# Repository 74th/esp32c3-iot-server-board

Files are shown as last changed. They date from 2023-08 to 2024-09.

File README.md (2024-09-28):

# IoT Server Board - ESP32C3

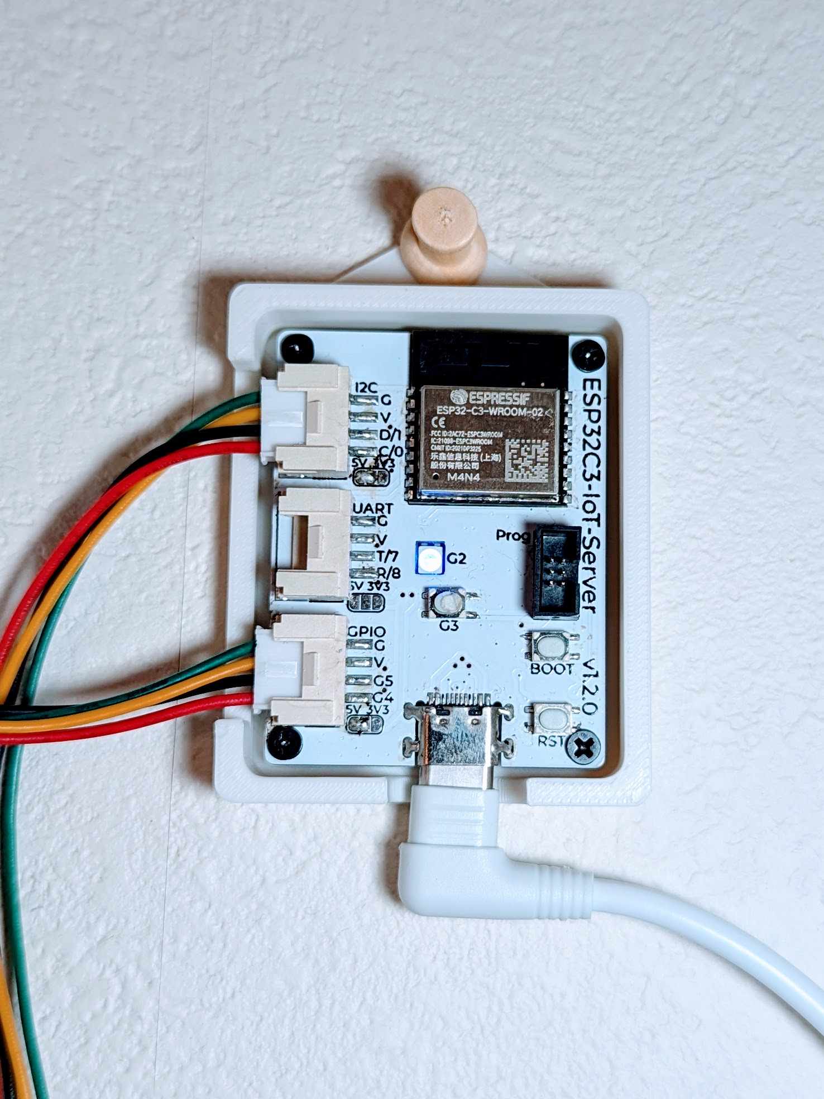
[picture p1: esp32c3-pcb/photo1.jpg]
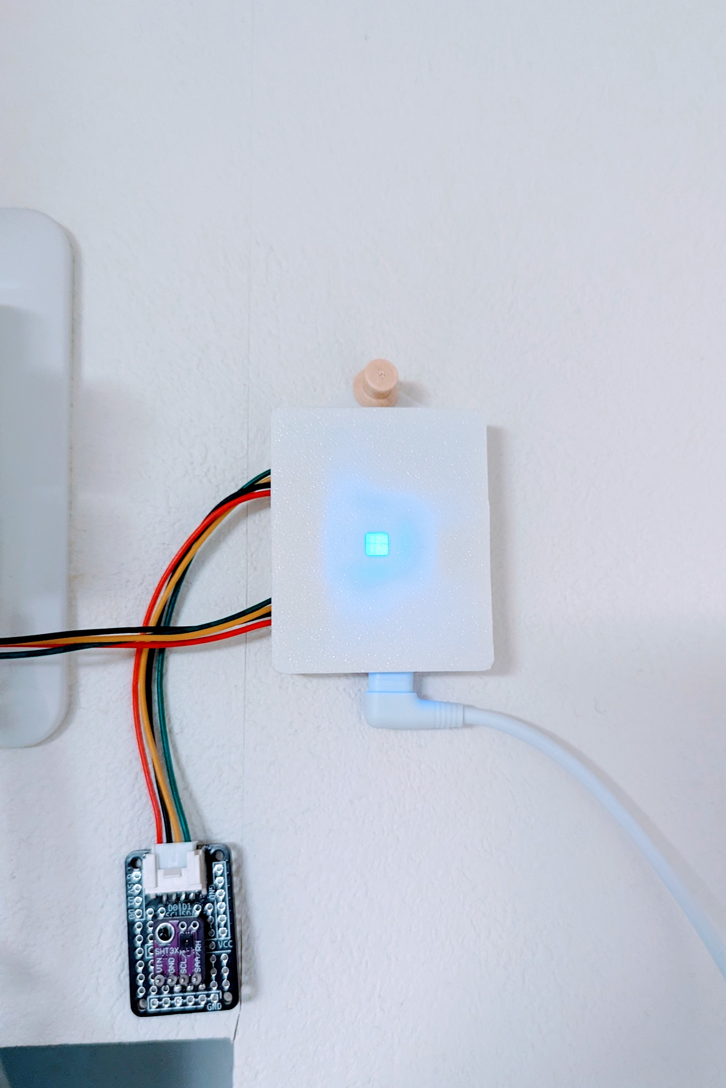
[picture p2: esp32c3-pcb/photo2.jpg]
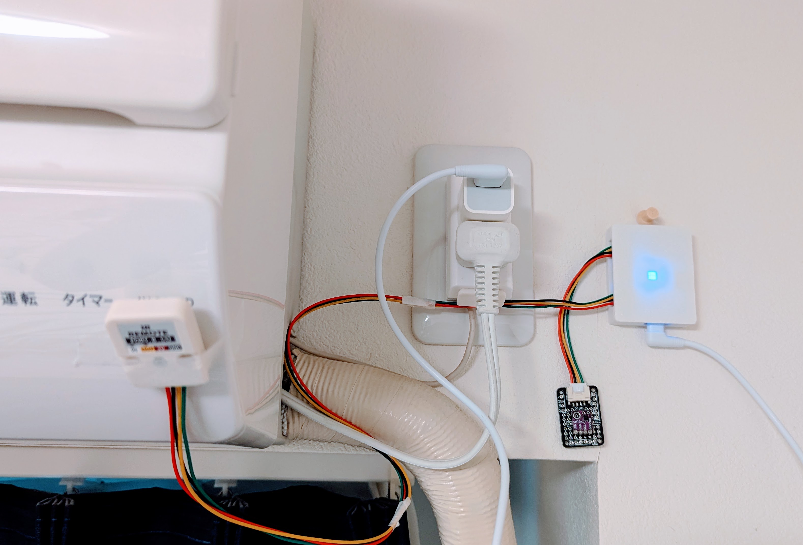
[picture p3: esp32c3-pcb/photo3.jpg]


Board for converting Grove device to IoT Server using ESP32-C3-WROOM-02.

ESP32-C3-WROOM-02 を使った Grove デバイスを IoT Server 化するためのボード。

74thが作成するファームウェアについてはこちら https://github.com/74th/esp32c3-iot-server-firmware

## features

- ESP32-C3 onboard for WiFi connectivity
- Three Grove ports are equipped.
- Selectable 5V or 3.3V VCC for Grove port
- RGB LED for indicator
- Button for operation
- USB Type-C port for firmware rewriting

### 🇯🇵

- ESP32-C3 搭載で、WiFi 接続が可能
- Grove ポートを 3 ポート搭載
- Grove ポートの VCC は 5V、3.3V を選択可能
- インジケータ用の RGB LED 搭載
- 操作用のボタン搭載
- USB Type-C ポートで、ファームウェアの書き換え可能

## v1.2.0

- Semantics: [PDF](./esp32c3-pcb/esp32c3-iot-server-v1.2.0-semantics.pdf) [kicanvas](https://kicanvas.org/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)
- PCB [kicanvas](https://kicanvas.org/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)

### BOM

| Reference | Name | Quantity |
| --- | --- | --- |
| C1 | Capacitor 0805 1uF | 1 |
| C2, C4 | Capacitor 0805 100nF | 2 |
| C3, C5-C8 | Capacitor 0805 10uF | 5 |
| CH1 | HY2.0 Socket SMD 4Pin - I2C | 1 |
| CH2 | HY2.0 Socket SMD 4Pin - UART | 1 |
| CH3 | HY2.0 Socket SMD 4Pin - GPIO | 1 |
| D1 | RGBLED 3528 SK6812MINI-E | 1 |
| J1 | Box Pin Header 2x3 Pitch 1.27mm | 1 |
| J2 | USB Type-C Receptacle - USB2.0_C_v3 | 1 |
| R1, R2 | Capacitor 0805 1kΩ (NC) | 2 |
| R3, R4, R10 | Capacitor 0805 10kΩ | 3 |
| R5, R9 | Capacitor 0805 5.1kΩ | 2 |
| R6, R7 | Capacitor 0805 10Ω | 2 |
| R8 | Capacitor 0805 56kΩ | 1 |
| SW1 | Button SKRPABE010 | 1 |
| SW2 | Button SKRPABE010 | 1 |
| SW3 | Button SKRPABE010 | 1 |
| U1 | WiFi MCU Module ESP32-C3-WROOM-02 | 1 |
| U2 | Regulator 3.3V SOT-223 AMS1117-3.3 | 1 |
| U3 | USB Power Protection IC SOT-23-6L CH217K | 1 |

## v1.1.1

### BOM

| Reference | Name | Quantity |
| --- | --- | --- |
| C1 | Capacitor 0805 1uF | 1 |
| C2, C3 | Capacitor 0805 100nF | 2 |
| C4, C5 | Capacitor 0805 10uF | 2 |
| CH1 | HY2.0 Socket SMD 4Pin - I2C | 1 |
| CH2 | HY2.0 Socket SMD 4Pin - UART | 1 |
| CH3 | HY2.0 Socket SMD 4Pin - GPIO | 1 |
| D1 | RGBLED 3528 SK6812MINI-E | 1 |
| F1 | PolyFuse 1812 KT6-1100SMDI (NC) | 1 |
| J1 | Box Pin Header 2x3 Pitch 1.27mm | 1 |
| J2 | USB Type-C Receptacle - USB2.0_C_v3 | 1 |
| R1, R2, R5-R7 | Capacitor 0805 10kF | 5 |
| R3, R4 | Capacitor 0805 5.1kF | 2 |
| R8 | Capacitor 0805 42kF | 1 |
| SW1 | Button SKRPABE010 | 1 |
| SW2 | Button SKRPABE010 | 1 |
| SW3 | Button SKRPABE010 | 1 |
| U1 | WiFi MCU Module ESP32-C3-WROOM-02 | 1 |
| U2 | Regulator 3.3V SOT-223 AMS1117-3.3 | 1 |
| U4 | USB Power Protection IC SOT-26 CH214K | 1 |

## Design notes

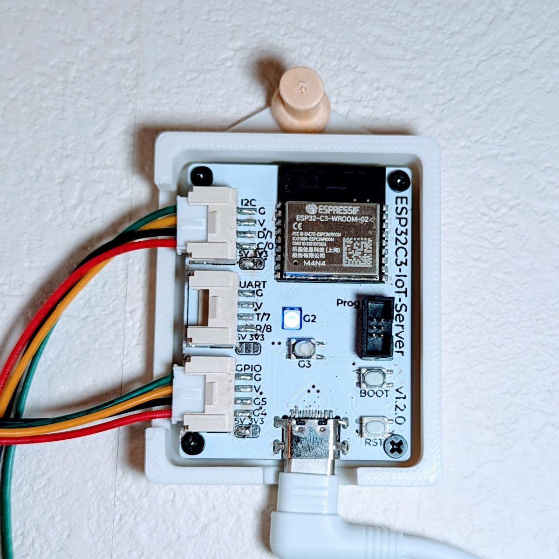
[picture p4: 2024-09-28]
esp32c3-pcb/g035-esp32c3-iot-server.jpg

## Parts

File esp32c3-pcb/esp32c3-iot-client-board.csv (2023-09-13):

Reference | Value | Footprint | 数量
C1 | 1u | $74th:Capacitor_0805_2012 | 1
C2, C4 | 100n | $74th:Capacitor_0805_2012 | 2
C3, C5-C8 | 10u | $74th:Capacitor_0805_2012 | 5
CH1 | I2C | $74th:HY2.0_Socket_SMD_4Pin | 1
CH2 | UART | $74th:HY2.0_Socket_SMD_4Pin | 1
CH3 | GPIO | $74th:HY2.0_Socket_SMD_4Pin | 1
D1 | SK6812MINI | $74th:YS-SK6812MINI-E-BACK-RIGHT | 1
J1 | Prog | $74th:BoxPinHeader_2x03_P1.27mm_Vertical | 1
J2 | USB2.0_C_v3 | $74th:USB-C-12-Pin-MidMount-ali-v5 | 1
JP1-JP3 | Jumper_3_Open | $74th:VCC_Selector_Jumper | 3
R1, R2 | 1k(NC) | $74th:Capacitor_0805_2012 | 2
R3, R4, R10 | 10k | $74th:Capacitor_0805_2012 | 3
R5, R9 | 5.1k | $74th:Capacitor_0805_2012 | 2
R6, R7 | 27.4 | $74th:Capacitor_0805_2012 | 2
R8 | 56k | $74th:Capacitor_0805_2012 | 1
SW1 | G3 | $74th:SKRPABE010 | 1
SW2 | BOOT | $74th:SKRPABE010 | 1
SW3 | RST | $74th:SKRPABE010 | 1
U1 | ESP32-C3-WROOM-02 | $74th-imported:ESP32-C3-WROOM-02 | 1
U2 | AMS1117-3.3 | Package_TO_SOT_SMD:SOT-223-3_TabPin2 | 1
U3 | CH217K | Package_TO_SOT_SMD:SOT-23-6 | 1

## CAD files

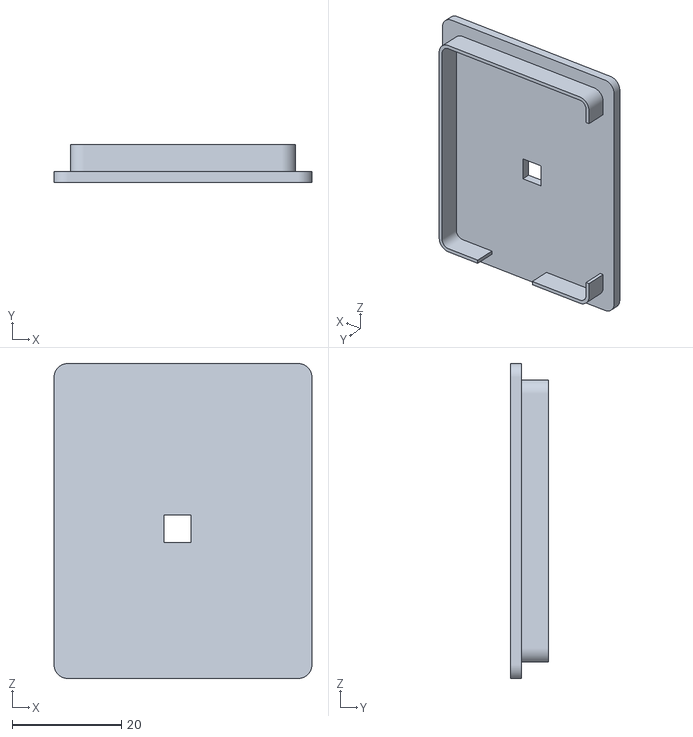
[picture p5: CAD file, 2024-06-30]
case/esp32c3-iot-client-board_case-lid_v1.1.0.stl
47.2 x 7.00 x 57.6

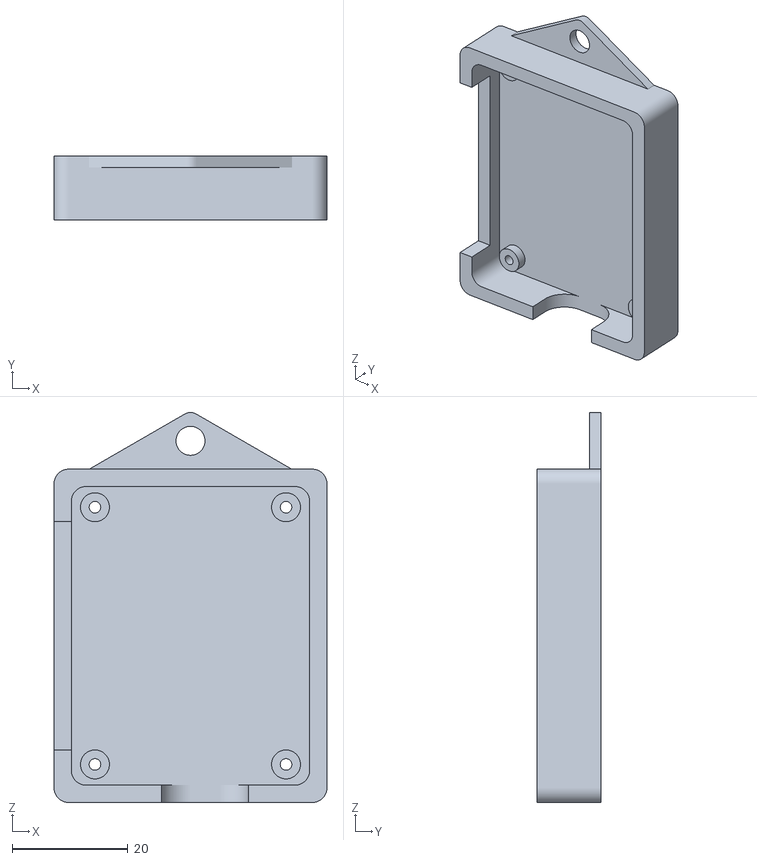
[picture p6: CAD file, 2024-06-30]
case/esp32c3-iot-client-board_case-bottom_v1.1.0.stl
47.2 x 11.0 x 67.4

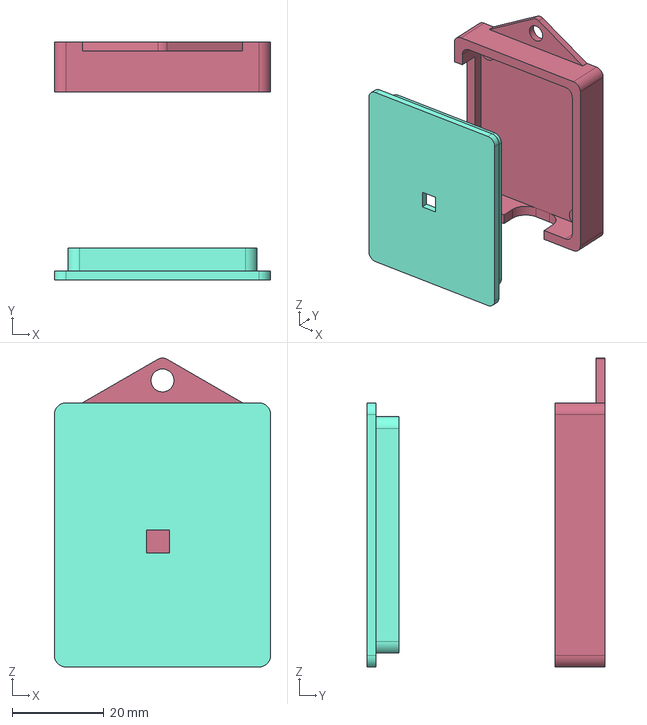
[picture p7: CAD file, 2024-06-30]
case/esp32c3-iot-client-board_case.FCStd
47.2 x 52.0 x 67.4 mm
lid

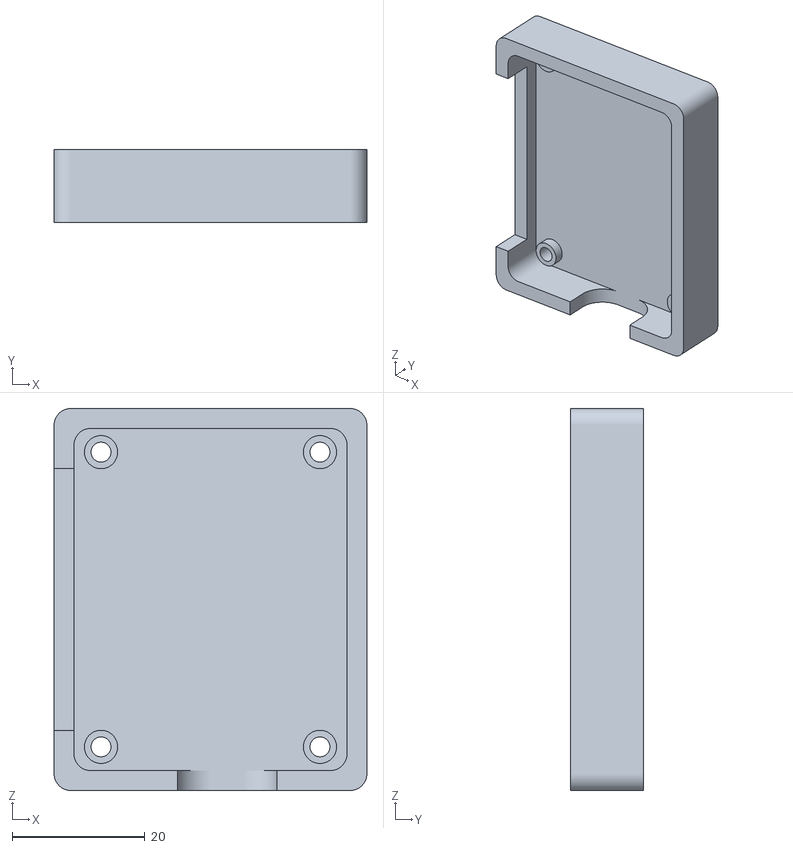
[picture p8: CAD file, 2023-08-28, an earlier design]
case/esp32c3-iot-client-board_case-bottom_v1.0.0.stl
47.2 x 11.0 x 57.6

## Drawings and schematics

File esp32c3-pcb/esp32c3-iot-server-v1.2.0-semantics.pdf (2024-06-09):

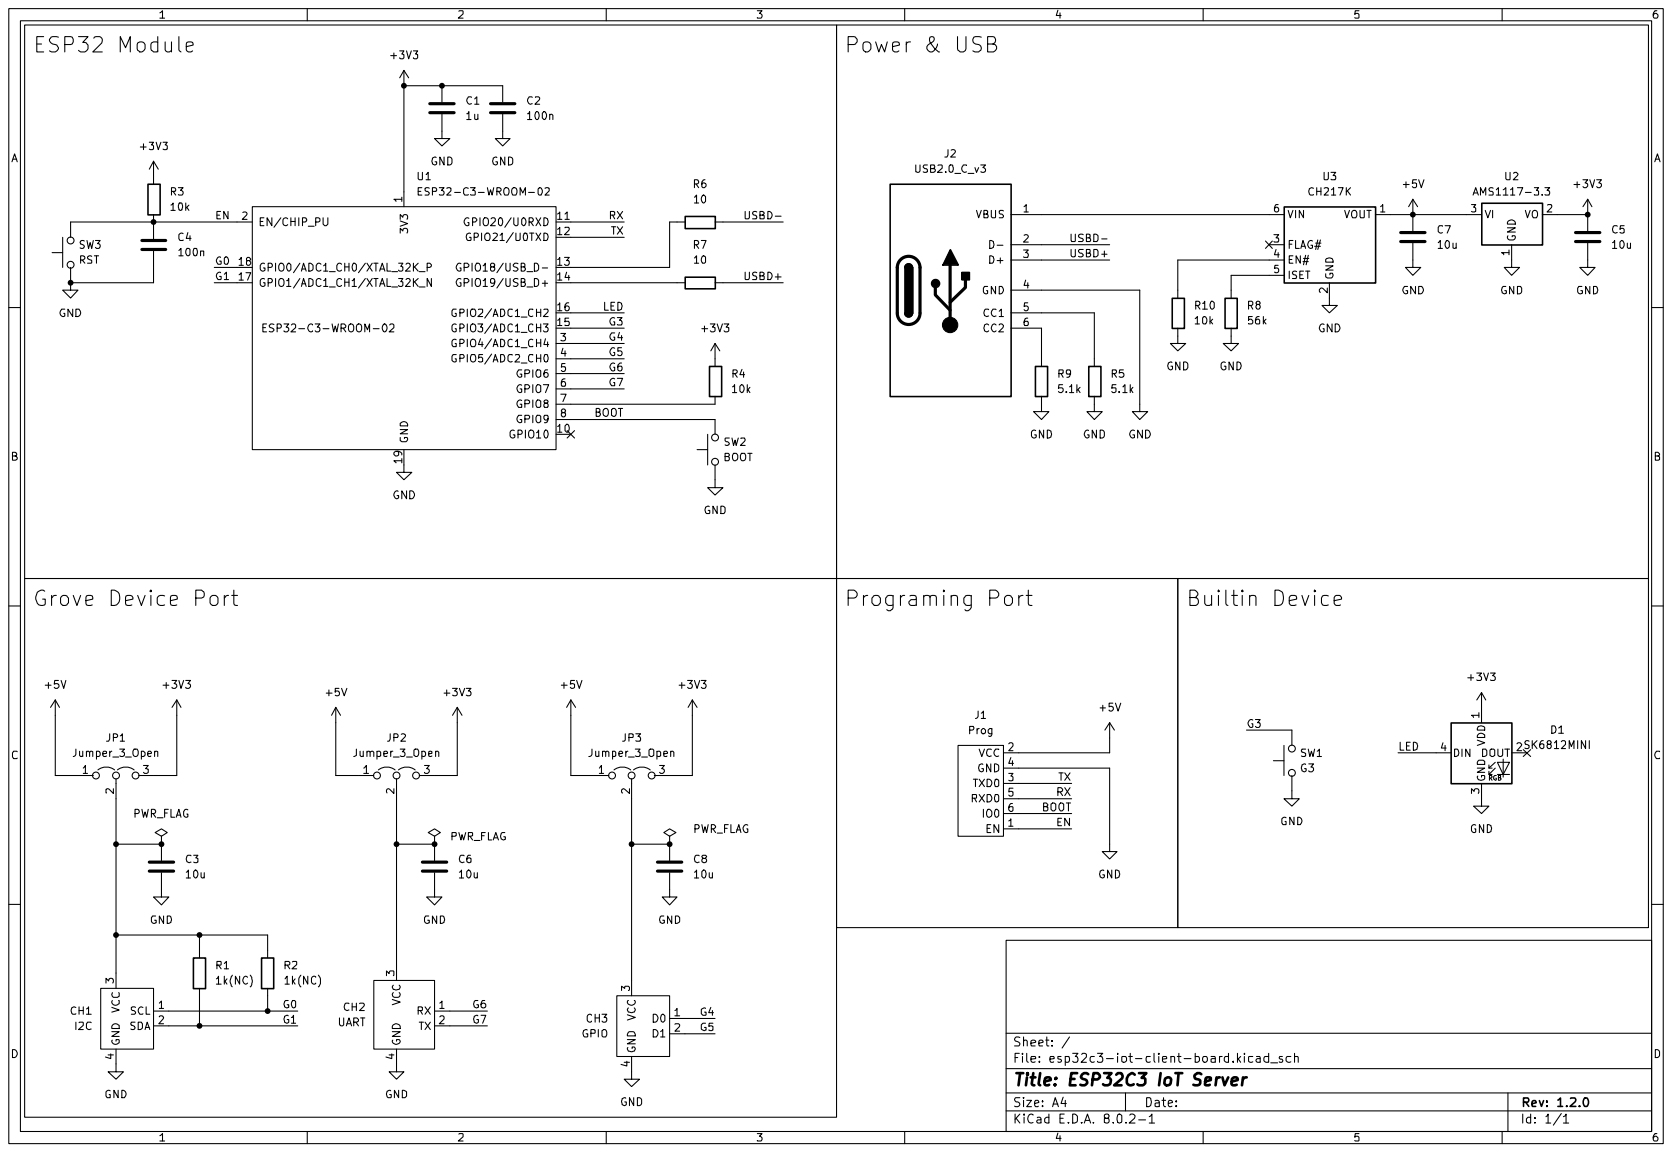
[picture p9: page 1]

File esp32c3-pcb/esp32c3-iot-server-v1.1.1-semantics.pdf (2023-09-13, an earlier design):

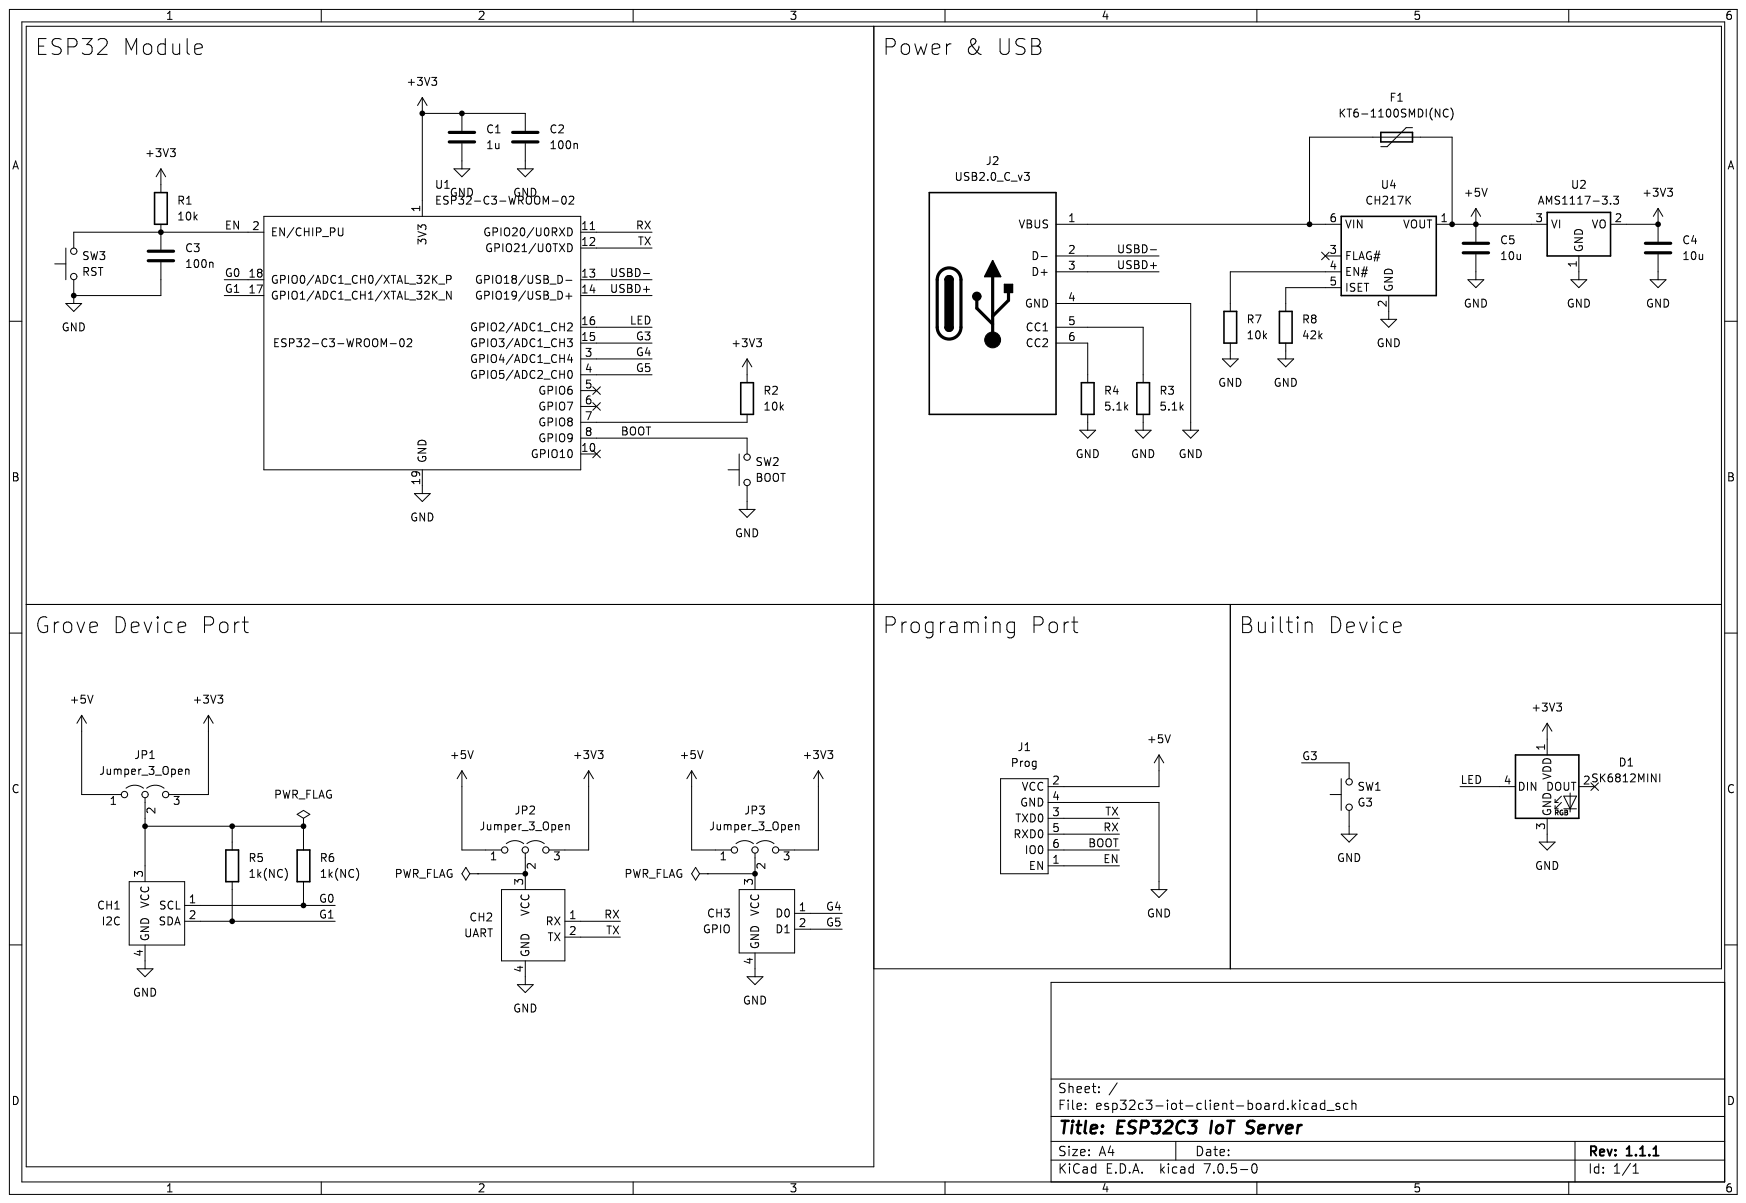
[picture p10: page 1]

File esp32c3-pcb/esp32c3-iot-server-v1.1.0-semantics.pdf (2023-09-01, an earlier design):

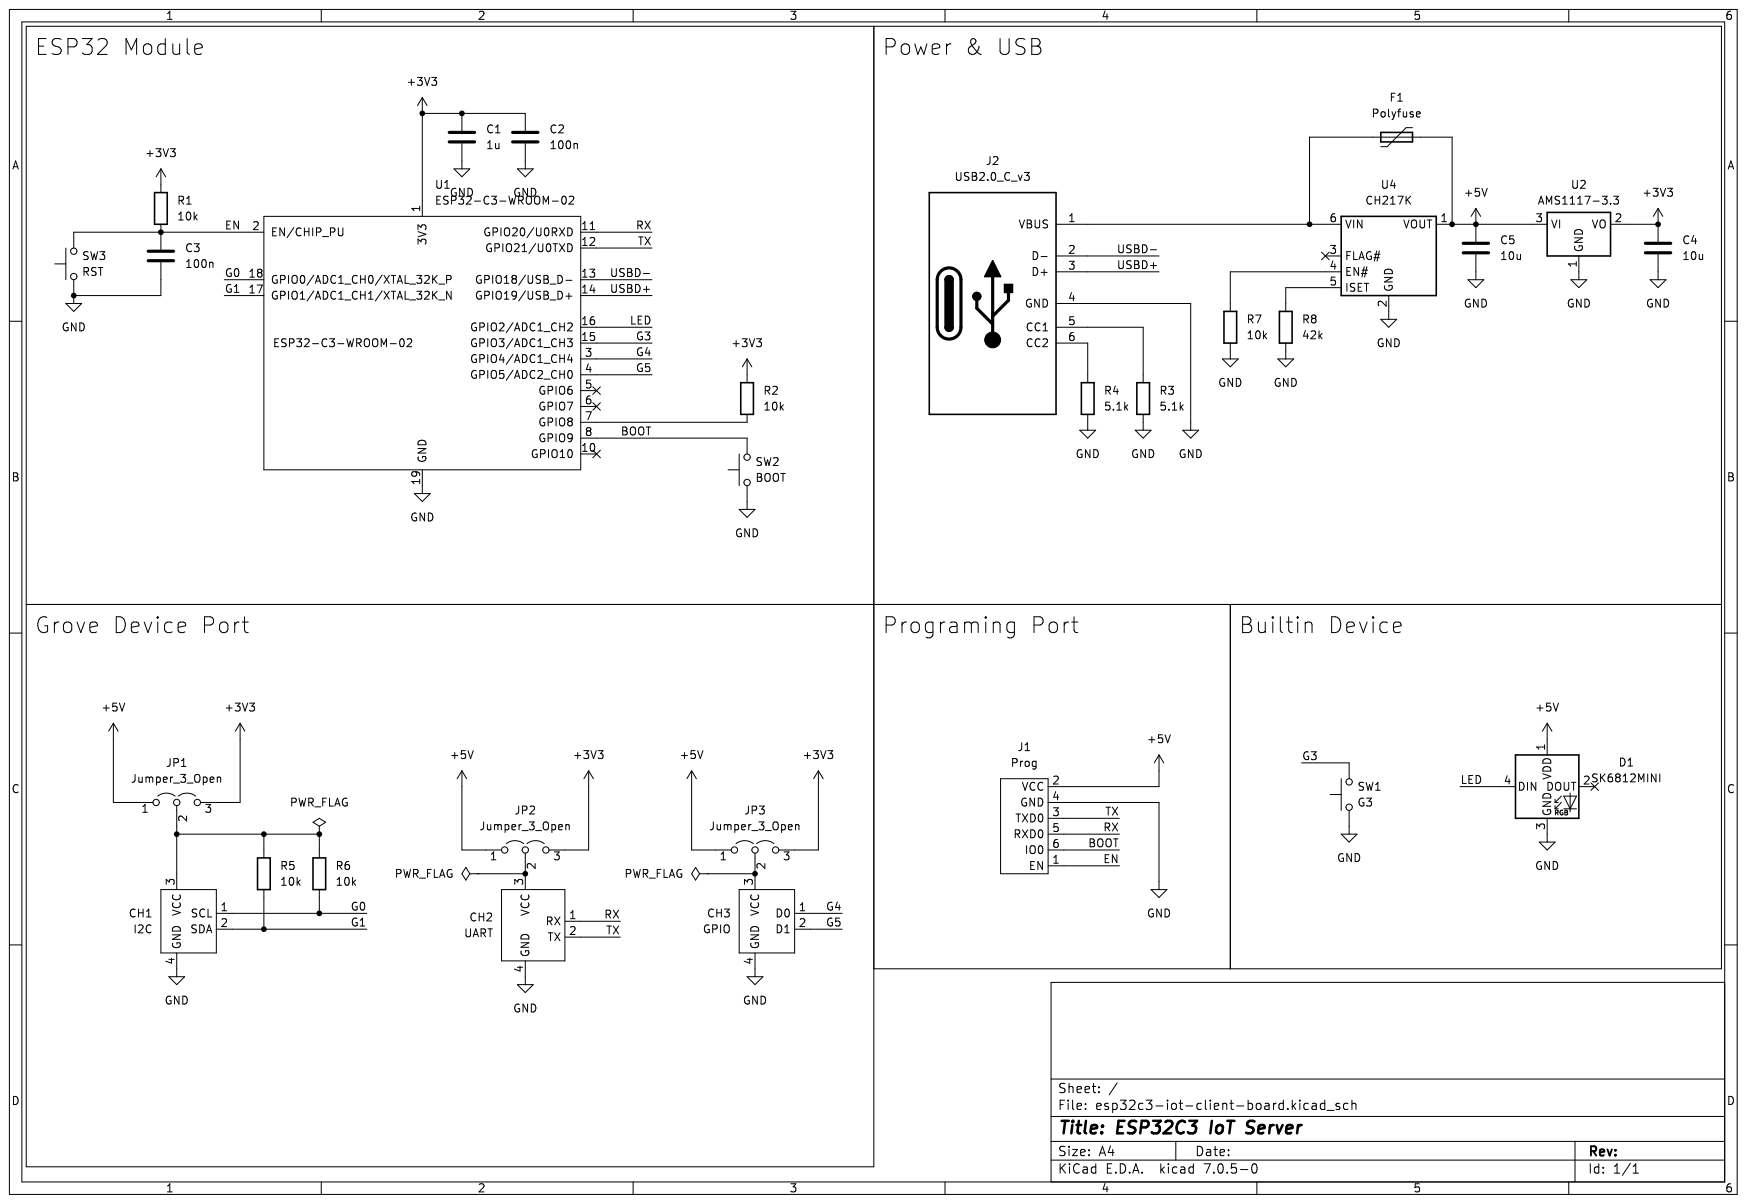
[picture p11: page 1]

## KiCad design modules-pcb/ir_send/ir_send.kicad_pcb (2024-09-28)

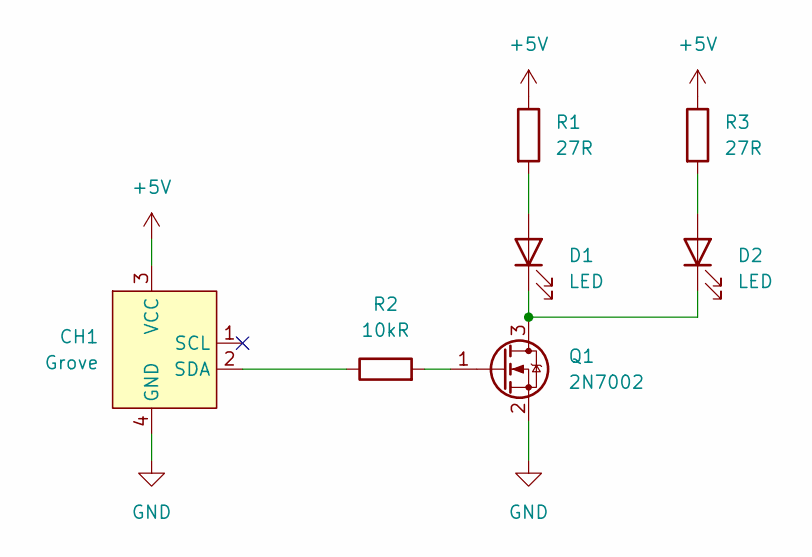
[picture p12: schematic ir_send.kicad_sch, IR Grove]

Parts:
CH1: Grove; Connector_HY-2.0_SMD_4Pin
D1, D2: LED; PinOut_Pin_2_1GND
Q1: 2N7002; Package_SOT-23
R1, R3: 27R; Register_0805_2012
R2: 10kR; Register_0805_2012

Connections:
+5V: CH1.3 (VCC), R1.1, R3.1
GND: CH1.4 (GND), Q1.2 (S)
unnamed: CH1.2 (SDA), R2.1
unnamed: D1.2 (A), R1.2
unnamed: D1.1 (K), D2.1 (K), Q1.3 (D)
unnamed: D2.2 (A), R3.2
unnamed: Q1.1 (G), R2.2

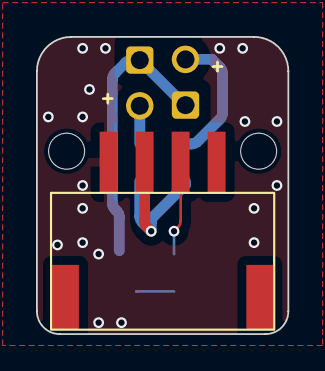
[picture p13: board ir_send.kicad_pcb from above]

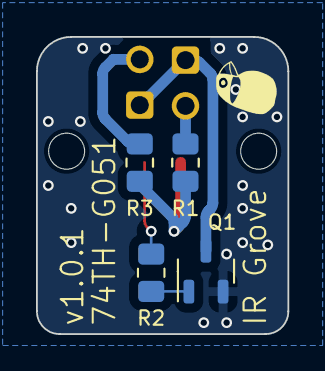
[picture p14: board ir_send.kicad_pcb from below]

Board: 2 copper layers, 14.0 x 16.5 mm, 10 parts (5 on the bottom side), 7 nets.

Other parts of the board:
M2, M2#2: Hole_M2_2.0
MISC-ICON: LOGO; Logo_74th_4mm

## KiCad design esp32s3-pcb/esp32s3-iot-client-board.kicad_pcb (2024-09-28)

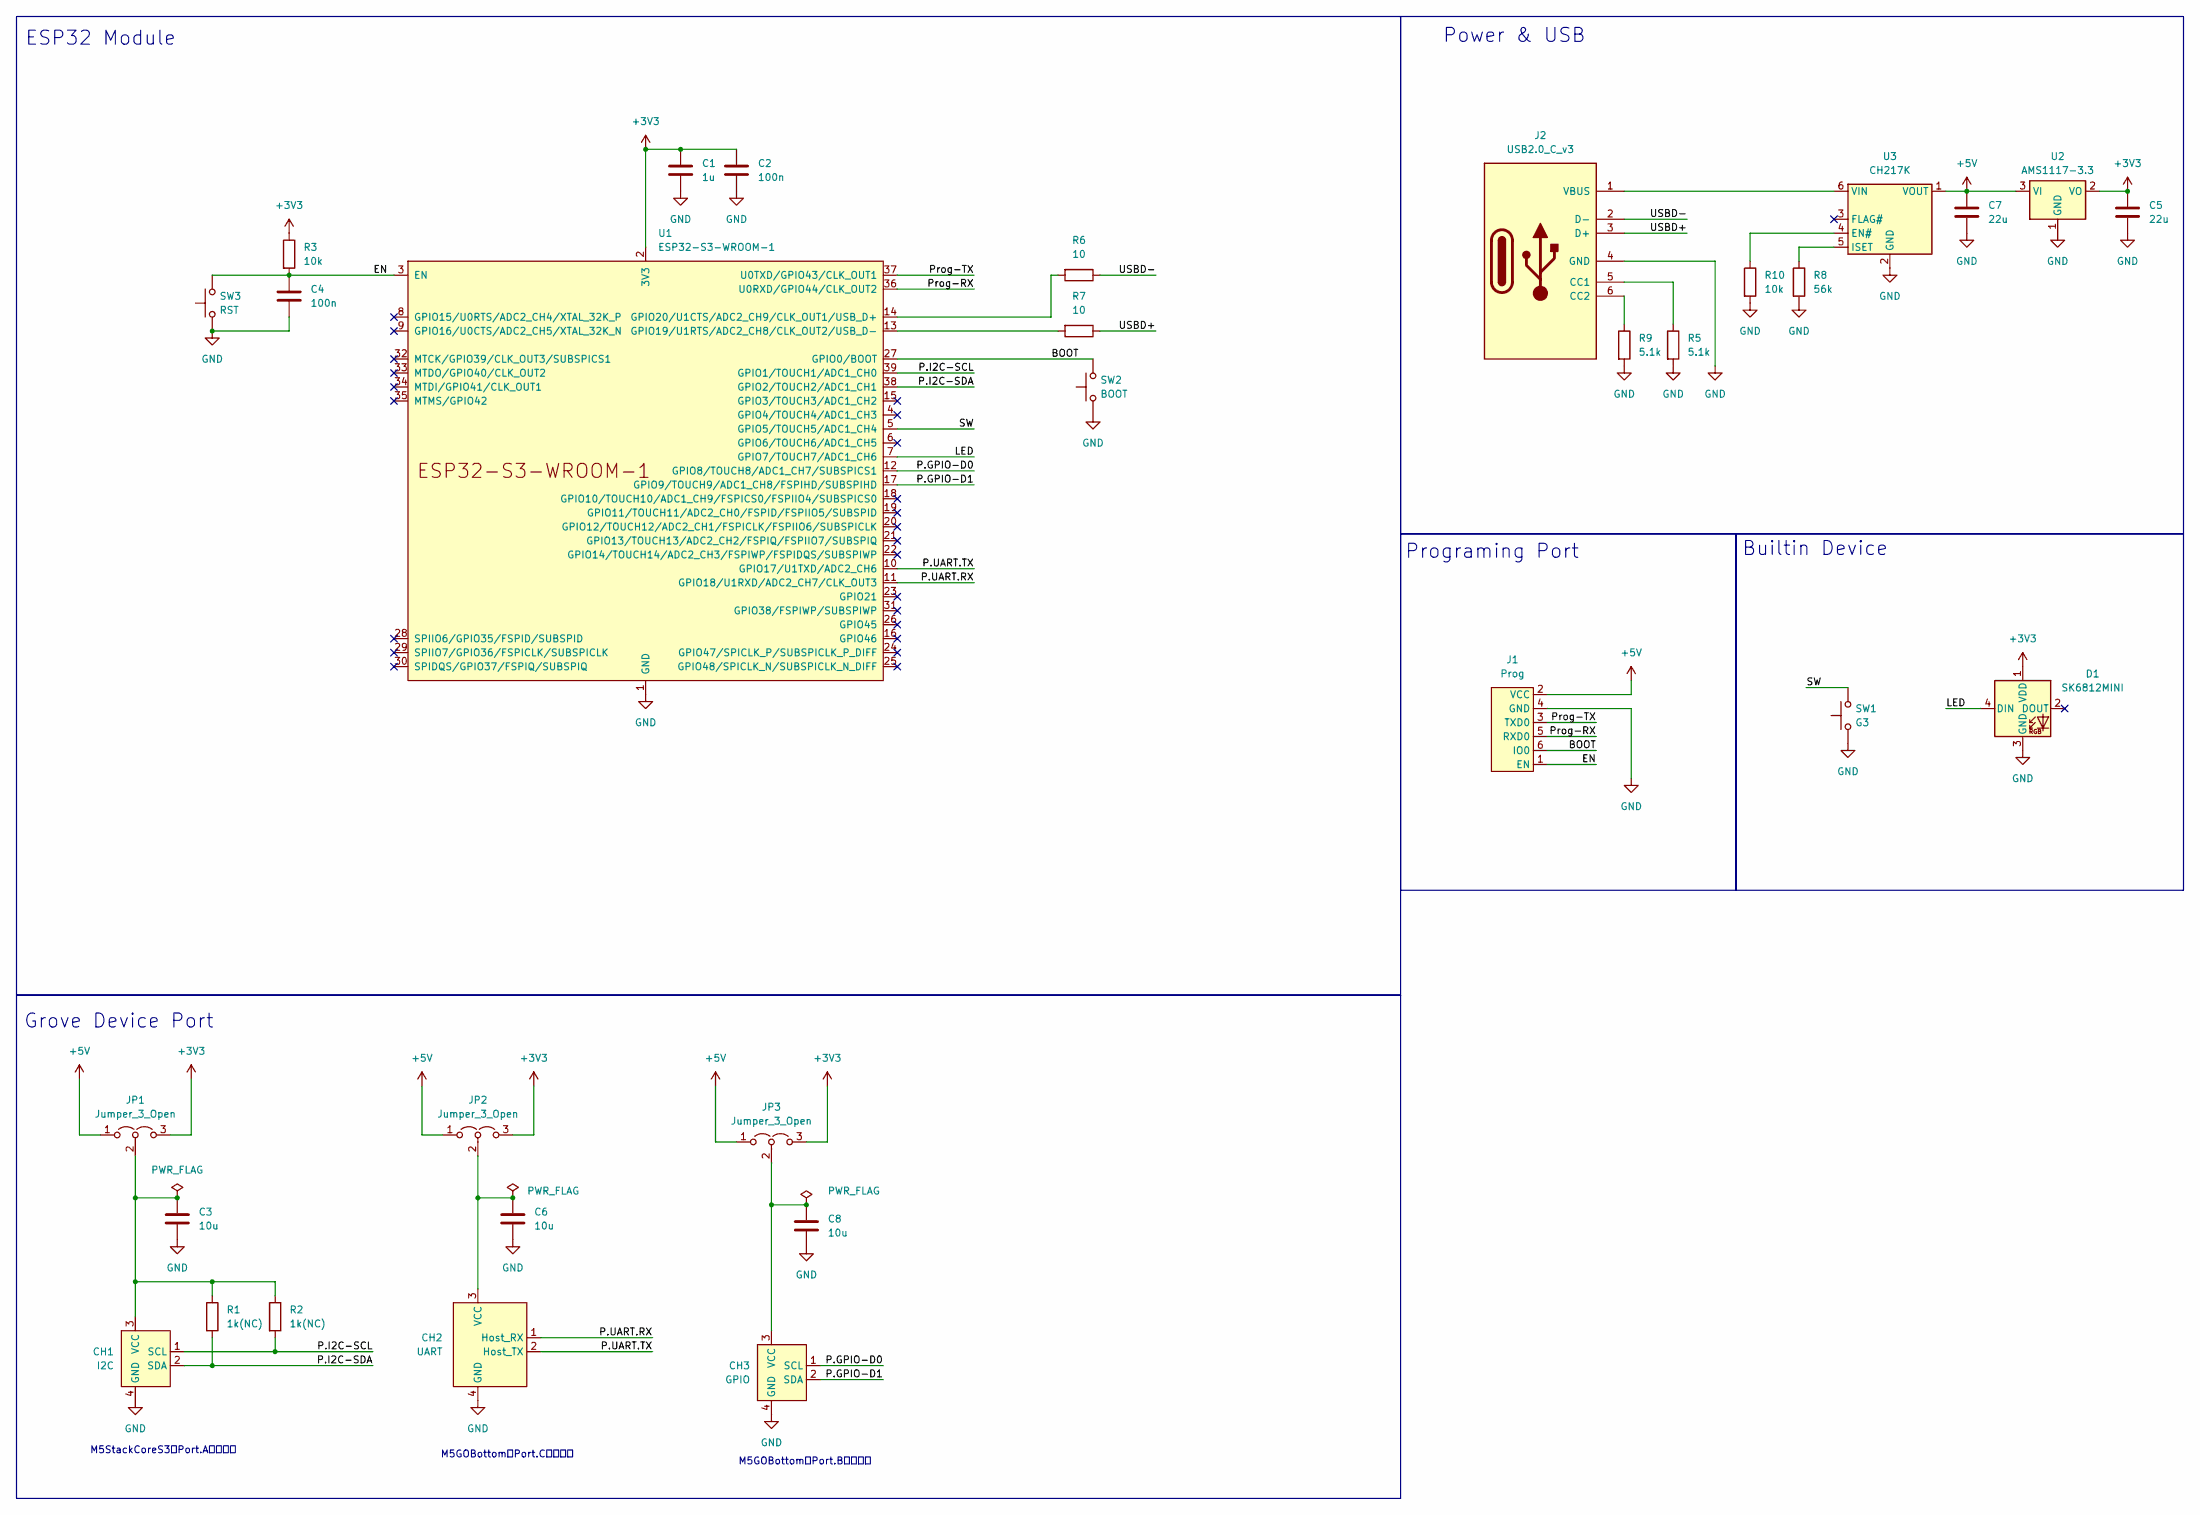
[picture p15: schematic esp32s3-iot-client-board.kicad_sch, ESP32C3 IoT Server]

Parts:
C1: 1u; Capacitor_0805_2012
C2, C4: 100n; Capacitor_0805_2012
C3, C6, C8: 10u; Capacitor_0805_2012
C5, C7: 22u; Capacitor_0805_2012
CH1: I2C; Connector_HY-2.0_SMD_4Pin
CH2: UART; Connector_HY-2.0_SMD_4Pin
CH3: GPIO; Connector_HY-2.0_SMD_4Pin
D1: SK6812MINI; LED_SK6812MINI-E_BACK-RIGHT
J1: Prog; Connector_BoxPinHeader_2x03_P1.27mm
J2: USB2.0_C_v3; Connector_USB-C-Receptacle_SMT_12-Pin_MidMount_Simple
JP1, JP2, JP3: Jumper_3_Open; SolderJumper-3
R1, R2: 1k(NC); Register_0805_2012
R3, R10: 10k; Register_0805_2012
R5, R9: 5.1k; Register_0805_2012
R6, R7: 10; Register_0805_2012
R8: 56k; Register_0805_2012
SW1: G3; Switch_SKRPABE010
SW2: BOOT; Switch_SKRPABE010
SW3: RST; Switch_SKRPABE010
U1: ESP32-S3-WROOM-1
U2: AMS1117-3.3; Package_SOT-223-3
U3: CH217K; Package_SOT-23-6

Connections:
+3V3: C1.1, C2.1, C5.1, D1.1 (VDD), JP1.3 (B), JP2.3 (B), JP3.3 (B), R3.1, U1.2 (3V3), U2.2 (VO)
+5V: C7.1, J1.2 (VCC), JP1.1 (A), JP2.1 (A), JP3.1 (A), U2.3 (VI), U3.1 (VOUT)
/BOOT: J1.6 (IO0), SW2.2, U1.27 (GPIO0/BOOT)
/EN: C4.1, J1.1 (EN), R3.2, SW3.2, U1.3 (EN)
/LED: D1.4 (DIN), U1.7 (GPIO7/TOUCH7/ADC1_CH6)
/P.GPIO-D0: CH3.1 (SCL), U1.12 (GPIO8/TOUCH8/ADC1_CH7/SUBSPICS1)
/P.GPIO-D1: CH3.2 (SDA), U1.17 (GPIO9/TOUCH9/ADC1_CH8/FSPIHD/SUBSPIHD)
/P.I2C-SCL: CH1.1 (SCL), R2.2, U1.39 (GPIO1/TOUCH1/ADC1_CH0)
/P.I2C-SDA: CH1.2 (SDA), R1.2, U1.38 (GPIO2/TOUCH2/ADC1_CH1)
/P.UART.RX: CH2.1 (Host_RX), U1.11 (GPIO18/U1RXD/ADC2_CH7/CLK_OUT3)
/P.UART.TX: CH2.2 (Host_TX), U1.10 (GPIO17/U1TXD/ADC2_CH6)
/Prog-RX: J1.5 (RXD0), U1.36 (U0RXD/GPIO44/CLK_OUT2)
/Prog-TX: J1.3 (TXD0), U1.37 (U0TXD/GPIO43/CLK_OUT1)
/SW: SW1.2, U1.5 (GPIO5/TOUCH5/ADC1_CH4)
/USBD+: J2.3 (D+), R7.1
/USBD-: J2.2 (D-), R6.1
GND: C1.2, C2.2, C3.2, C4.2, C5.2, C6.2, C7.2, C8.2, CH1.4 (GND), CH2.4 (GND), CH3.4 (GND), D1.3 (GND), J1.4 (GND), J2.4 (GND), R5.2, R8.2, R9.2, R10.2, SW1.1, SW2.1, SW3.1, U1.1 (GND), U1.40 (GND), U1.41 (GND), U2.1 (GND), U3.2 (GND)
unnamed: C3.1, CH1.3 (VCC), JP1.2 (C), R1.1, R2.1
unnamed: C6.1, CH2.3 (VCC), JP2.2 (C)
unnamed: C8.1, CH3.3 (VCC), JP3.2 (C)
unnamed: J2.5 (CC1), R5.1
unnamed: J2.6 (CC2), R9.1
unnamed: J2.1 (VBUS), U3.6 (VIN)
unnamed: R7.2, U1.13 (GPIO19/U1RTS/ADC2_CH8/CLK_OUT2/USB_D-)
unnamed: R6.2, U1.14 (GPIO20/U1CTS/ADC2_CH9/CLK_OUT1/USB_D+)
unnamed: R10.1, U3.4 (EN#)
unnamed: R8.1, U3.5 (ISET)

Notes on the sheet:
ESP32 Module
Builtin Device
M5StackCoreS3のPort.Aに基づく
M5GOBottomのPort.Bに基づく
M5GOBottomのPort.Cに基づく
Programing Port
Grove Device Port
Power & USB

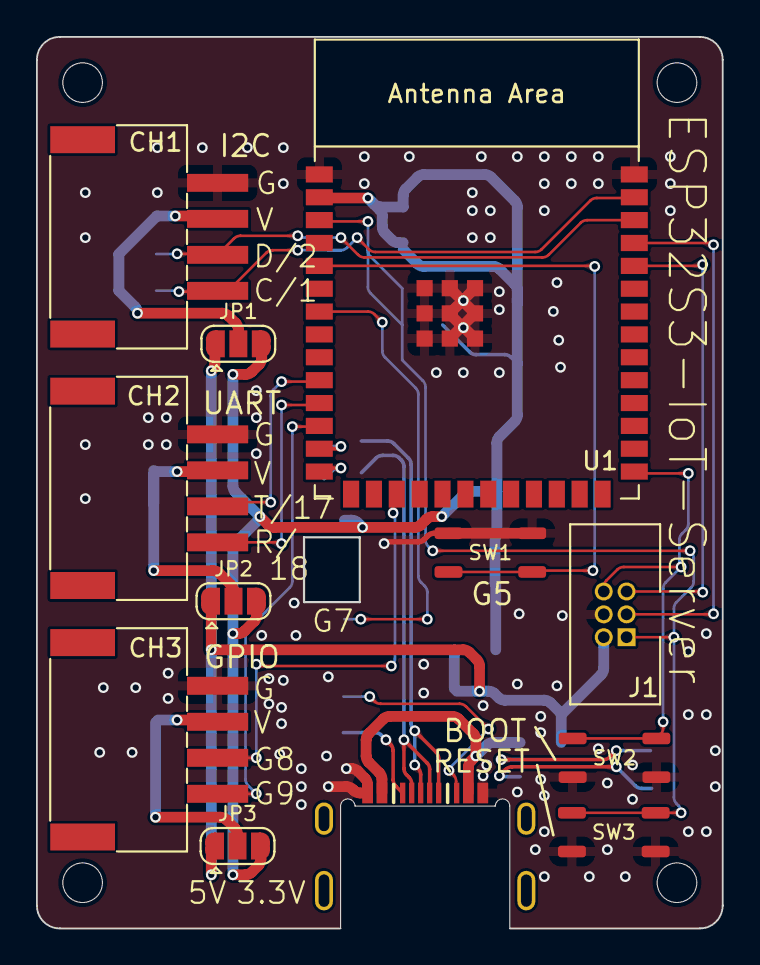
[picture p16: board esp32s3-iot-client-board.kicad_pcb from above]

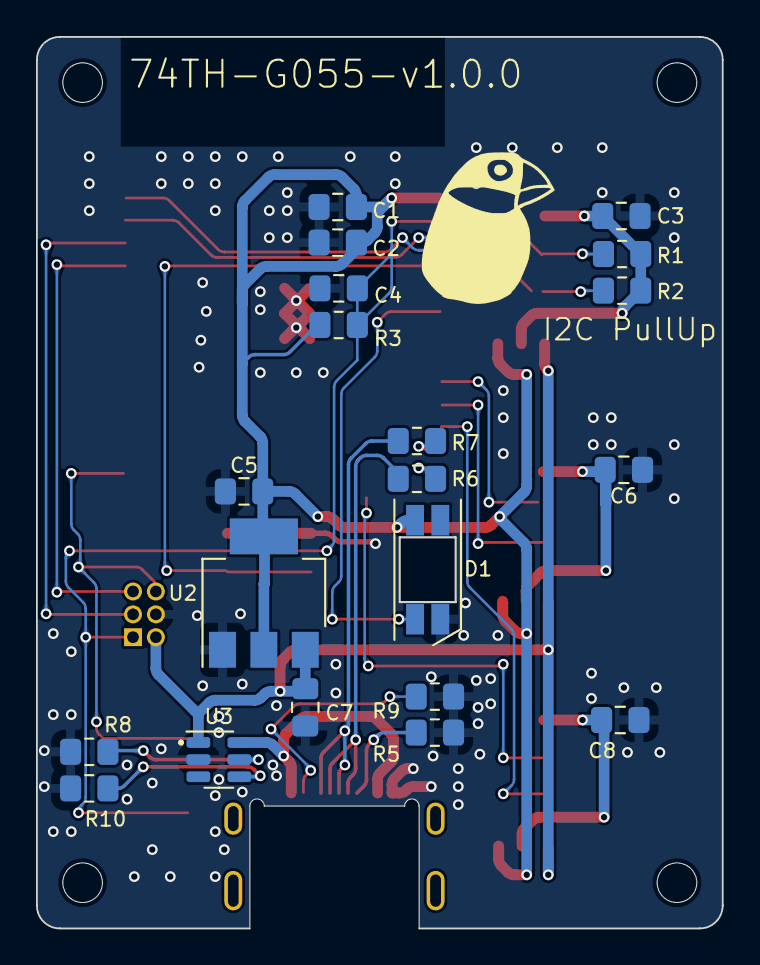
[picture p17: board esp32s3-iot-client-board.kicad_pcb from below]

Board: 2 copper layers, 38.1 x 49.5 mm, 36 parts (20 on the bottom side), 27 nets.

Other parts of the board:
M1, M2, M3, M4: M2-Hole

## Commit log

2023-08-28 update case
    [case-bottom-Body.stl, case-bottom-BodyPocket004.stl, case-bottom.FCStd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]
2023-08-28 organize folder
    [case-bottom.FCStd, esp32c3-iot-client-board.kicad_pcb, esp32c3-iot-client-board.kicad_sch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]
2023-09-01 update document
    [esp32c3-iot-client-board.csv, esp32c3-iot-client-board.kicad_sch]
2024-06-09 dumping register
    [esp32c3-iot-client-board.kicad_sch]
2024-06-30 ir send module
    [ir_send.kicad_pcb, ir_send.kicad_sch]
